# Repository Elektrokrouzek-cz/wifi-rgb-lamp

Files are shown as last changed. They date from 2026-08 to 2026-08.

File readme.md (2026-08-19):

# Wifi RGB LED Lamp
This is the construction of Wifi controlled RGB LED lamp. It is based on ESP32-C3 super mini 
module and WS2812B LED strip and WLED project.

PCB is 2-layer and was designed using KiCad 10. Fabrication output for JLCPCB is in 
gerber folder.

**Happy soldering!**

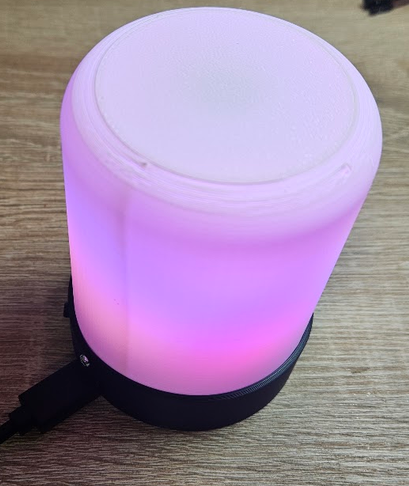
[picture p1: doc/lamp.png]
Lamp


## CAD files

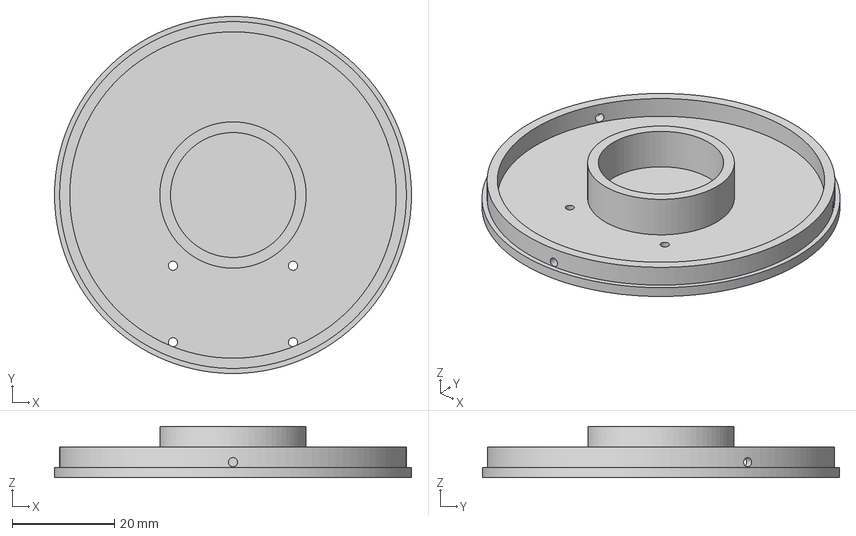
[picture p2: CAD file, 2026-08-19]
3d/lamp_middle.3mf
70.0 x 70.0 x 10.0 mm

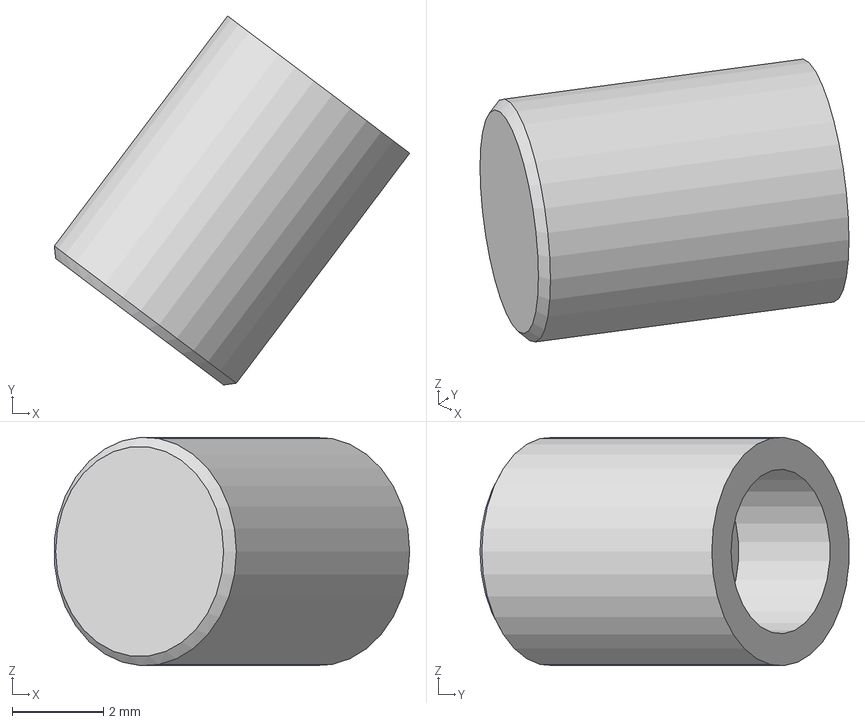
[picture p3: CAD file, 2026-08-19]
3d/lamp_button.3mf
7.77 x 8.07 x 4.99 mm

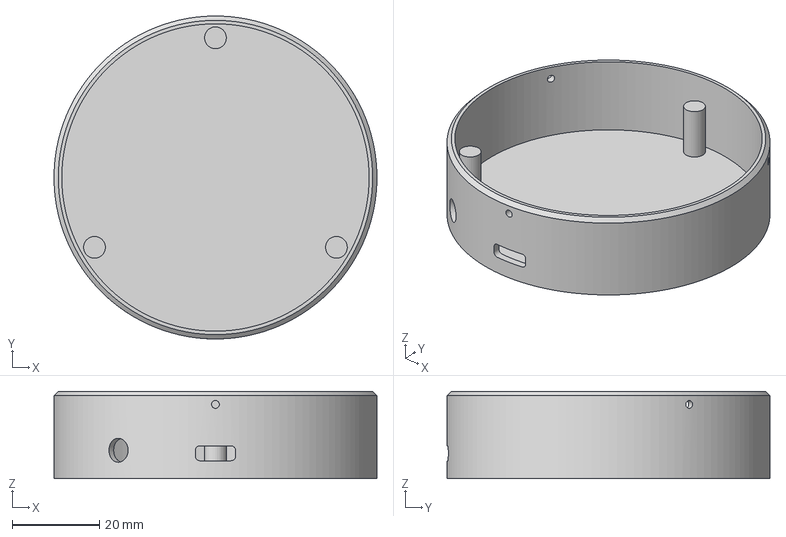
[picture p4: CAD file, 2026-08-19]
3d/lamp_bottom.3mf
74.0 x 74.0 x 20.0 mm

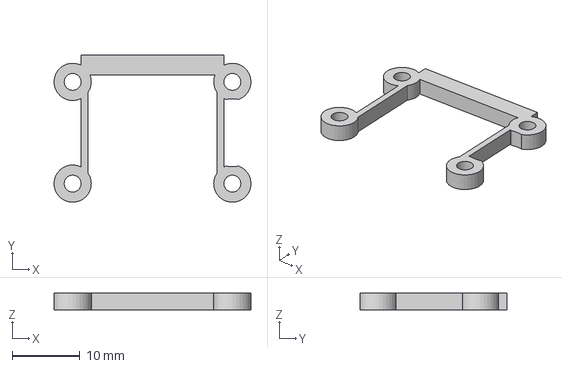
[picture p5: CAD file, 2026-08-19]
3d/lamp_pcb_spacer.3mf
29.1 x 21.7 x 2.50 mm

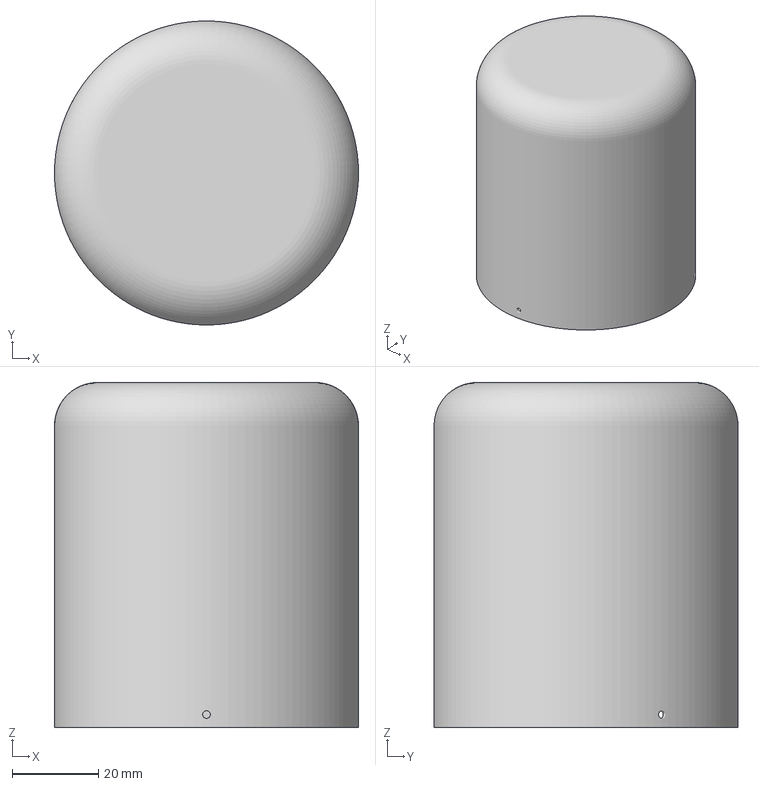
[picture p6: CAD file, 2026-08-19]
3d/lamp_cover.3mf
70.5 x 70.5 x 80.0 mm

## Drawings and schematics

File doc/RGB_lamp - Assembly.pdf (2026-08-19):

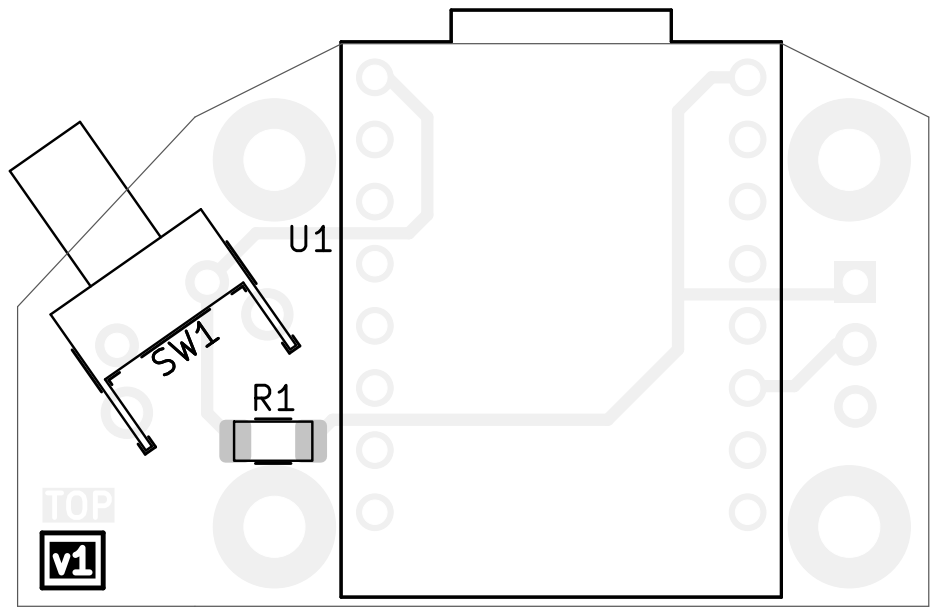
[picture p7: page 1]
D Date:; Size: A4; Rev:

Board2Pdf: Black And White TOP - Page 1/2

Sheet: Black And White TOP
File: rgb_lamp.kicad_pcb
Title:
KiCad E.D.A. 10.0.3

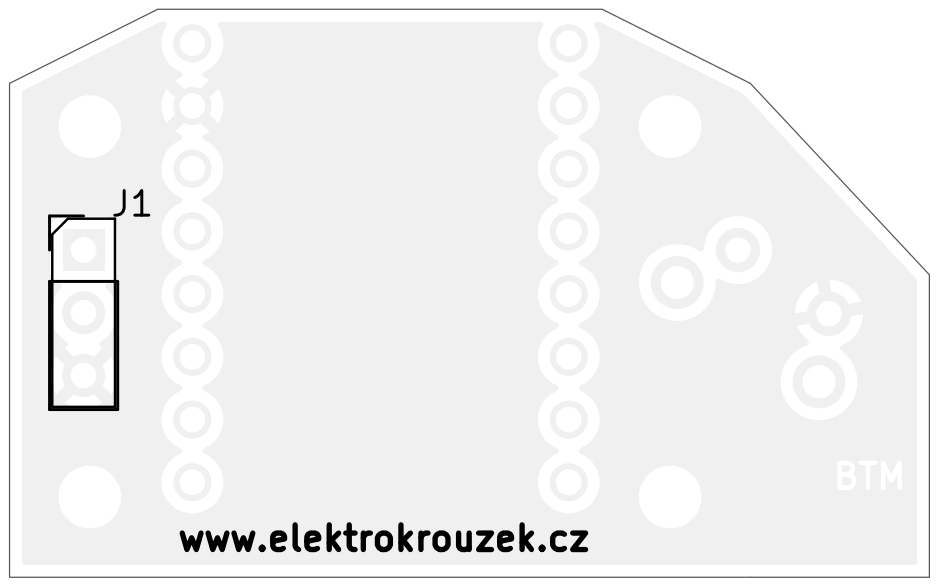
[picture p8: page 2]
D Date:; Size: A4; Rev:

www.elektrokrouzek.cz

Board2Pdf: Black And White BOT - Page 2/2

Sheet: Black And White BOT
File: rgb_lamp.kicad_pcb
Title:
KiCad E.D.A. 10.0.3

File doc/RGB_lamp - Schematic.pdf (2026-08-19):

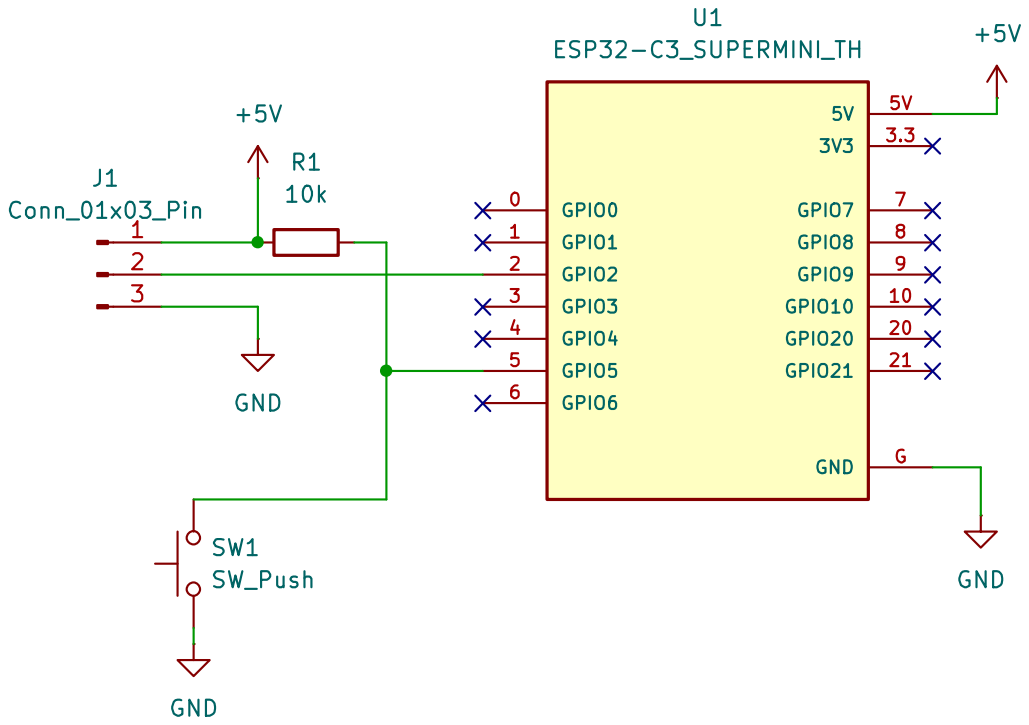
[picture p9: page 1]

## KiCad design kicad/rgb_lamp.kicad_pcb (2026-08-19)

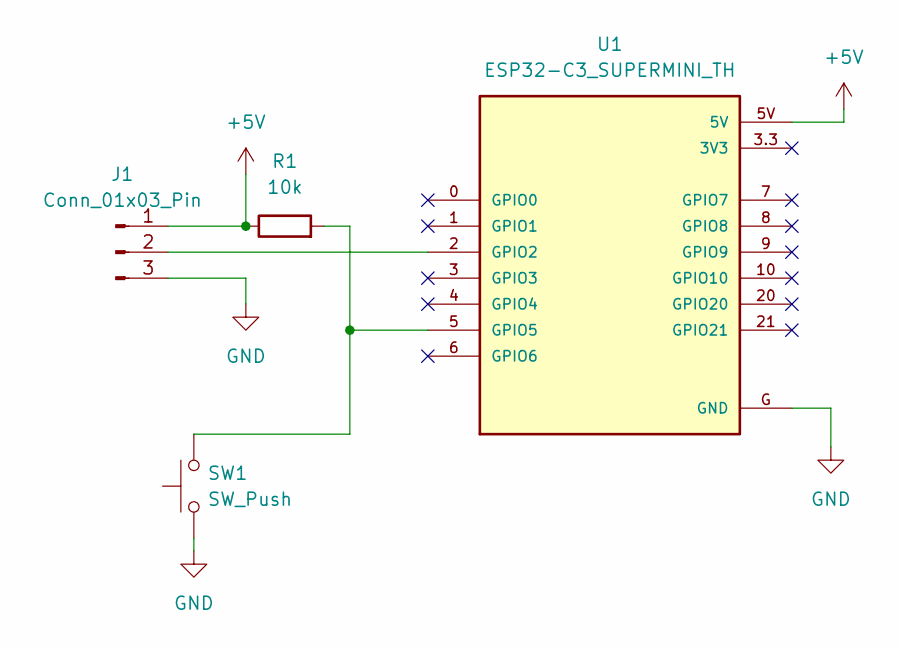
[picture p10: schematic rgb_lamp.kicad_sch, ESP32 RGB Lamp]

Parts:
J1: Conn_01x03_Pin; PinHeader_1x03_P2.54mm_Vertical
R1: 10k; R_1206_3216Metric_Pad1.30x1.75mm_HandSolder
SW1: SW_Push; SW_Tactile_SPST_Angled_PTS645Vx83-2LFS
U1: ESP32-C3_SUPERMINI_TH; MODULE_ESP32-C3_SUPERMINI

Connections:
+5V: J1.1, R1.1, U1.5V
GND: J1.3, SW1.1, U1.G (GND)
unnamed: J1.2, U1.2 (GPIO2)
unnamed: R1.2, SW1.2, U1.5 (GPIO5)

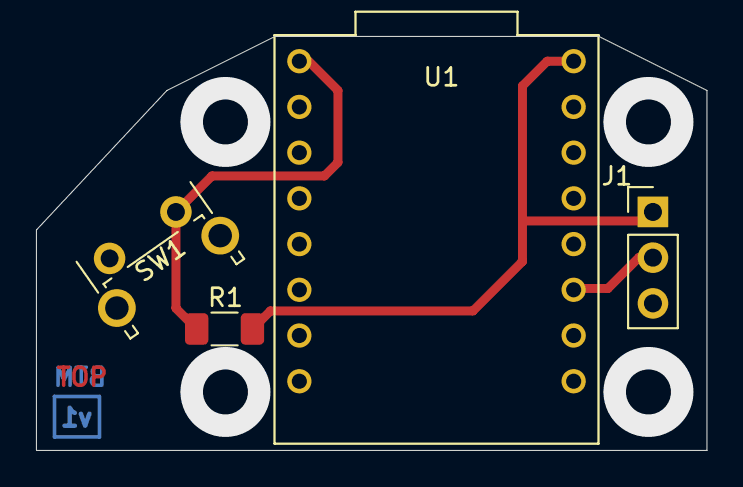
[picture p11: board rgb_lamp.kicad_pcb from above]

Board: 2 copper layers, 37.2 x 23.0 mm, 4 parts (0 on the bottom side), 4 nets.

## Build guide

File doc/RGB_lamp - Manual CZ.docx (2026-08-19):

# RGB Lampička

## Popis zapojení

Toto je velmi jednoduchá konstrukce WiFi RGB lampičky s LED páskem, která je založená na modulu ESP32-C3 super mini a projektu WLED.

## Popis sestavení

Konstrukce má součástky z jedné strany plošného spoje. Modul ESP32-C3 je do desky osazen pomocí kolíkových lišt. Jediná problematická součástka je rezistor R1 v pouzdře SMD o velikosti 1206. Vodiče k LED pásku jsou připojeny z druhé strany plošného spoje. Můžeme si opět pomoci kolíkovou lištou.

Pozor: Při zapojování LED pásku dbejte na polaritu napájení. Při přepólování by mohlo dojít k jeho zničení.

## Oživení

Nejprve je nutné naflashovat do modulu firmware WLED. Nejjednodušší způsob je pomocí webového rozhraní na adrese https://install.wled.me/. Použijte prohlížeč Chrome, který dobře funguje se sériovým rozhraním.

Postup:

1. Připojte modul pomocí USB kabelu k PC
2. Na modulu držte tlačítko BOOT a krátce stiskněte tlačítko RESET (BOOT je nutné držet během mačkání RESET)
3. Pusťte tlačítko BOOT
4. Na webu nechte výchozí nastavení a klikněte na Install

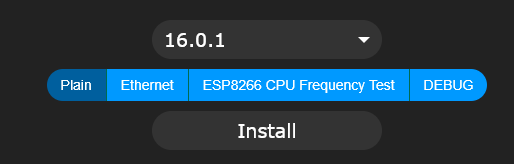
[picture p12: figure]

5. Vyberte sériový port modulu a klikněte na tlačítko Připojení
6. Vyberte Install WLED

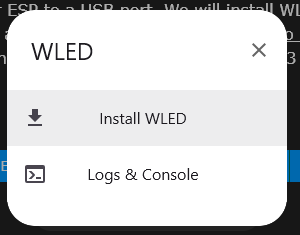
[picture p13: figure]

7. Zaškrtněte Erase device a poté klikněte na next. Potvrďte instalaci kliknutím na Install.

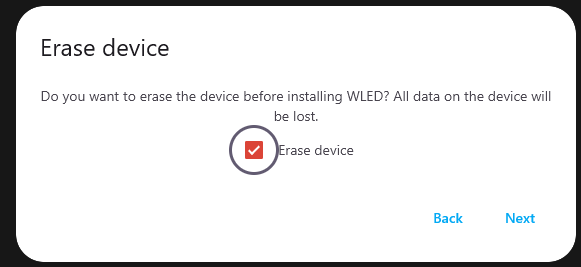
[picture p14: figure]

8. Instalace typicky zabere pouze pár sekund

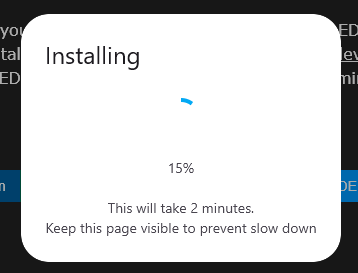
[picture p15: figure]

9. Odpojte a znovu připojte modul k USB
10. Nyní je nutné nastavit připojení modulu k vaší WiFi síti. Modul je nyní v režimu přístupového bodu a je nutné se k němu připojit. Na počítači nebo telefonu vyhledejte síť WLED-AP a připojte se k ní.

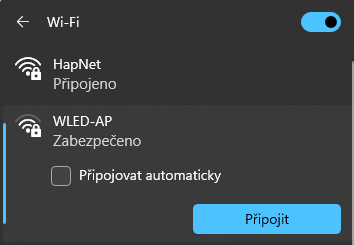
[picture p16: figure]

11. Měla by se automaticky otevřít úvodní stránka s nastavením. Klikněte na WIFI SETTINGS

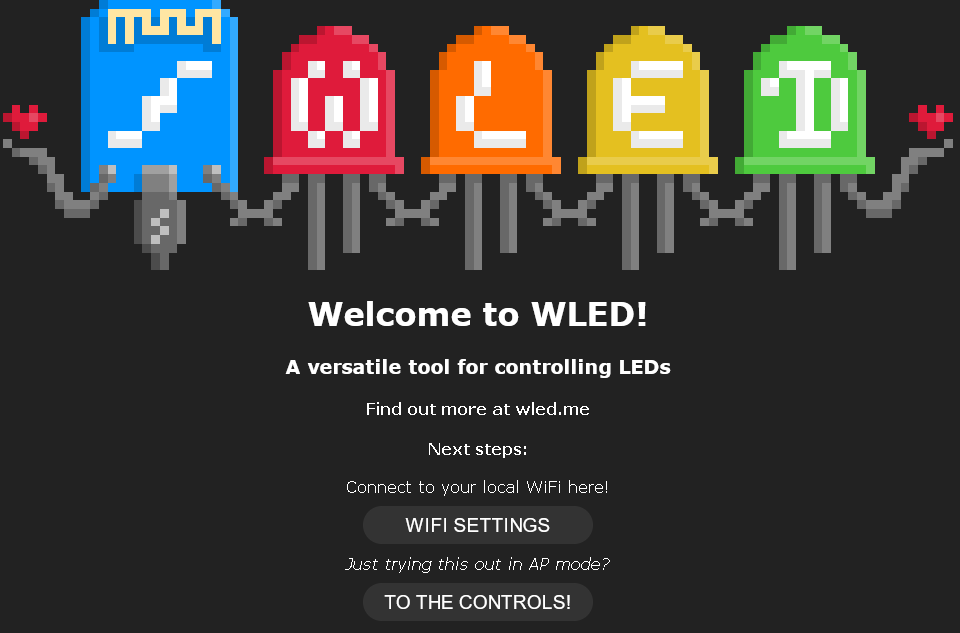
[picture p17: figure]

12. Vložte název vaší místní WiFi sítě a heslo. Následně klikněte na Save & Connect

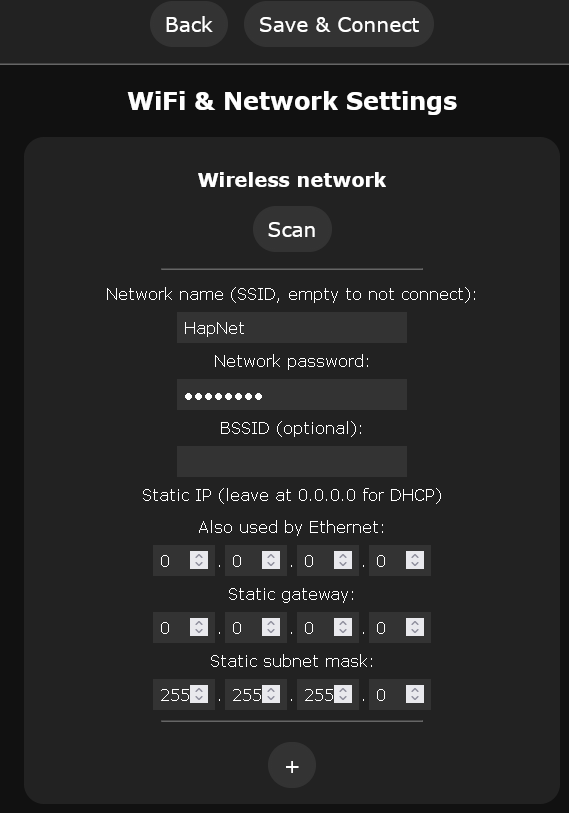
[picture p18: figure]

13. Nyní se modul restartuje a měl by se připojit k lokální síti.
14. Nainstalujte na vašem mobilním telefonu aplikaci WLED z Google Play

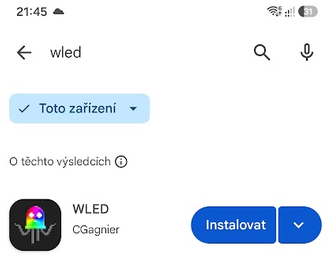
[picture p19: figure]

15. Po otevření aplikace my měl být vidět váš modul. Nyní je vše hotovo – můžete si nastavit svit vaší lampičky

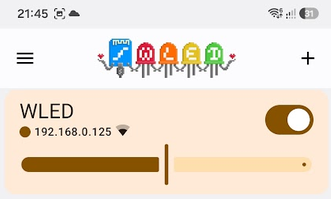
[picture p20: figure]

16. Konstrukce je zapojená tak, aby fungovalo výchozí nastavení – LED diody by měly svítit. Tlačítko je připojeno na GPIO5 a je nutné jej nastavit v záložce Config

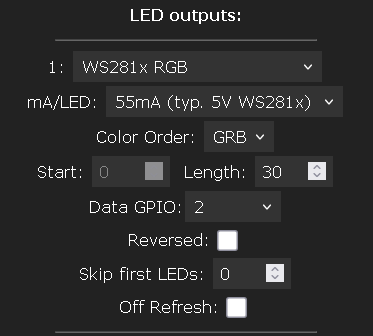
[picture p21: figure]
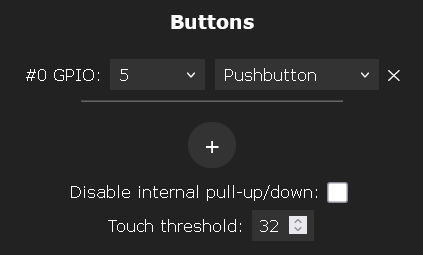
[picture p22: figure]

## Seznam součástek

Označení | Hodnota | Počet
R1 | 10k, 1206 | 1
U1 | ESP32-C3 super mini | 1
SW1 | Tlačítko 6x6mm, 90° | 1
J1 | Připojení vodičů k LED pásku
| Kolíková lišta pro U1, 2.54mm, 8 pin | 2
| RGB LED pásek WS2812B, 50cm, 60 LED/m | 50cm
| Samořezné šroubky 2.2x6.5mm (Bossard 1376012) | 7

## 3D tisk

Pro tisk krytu lampičky byl využit běžný bílý PLA filament. Rozptyluje světlo lépe než filament transparentní. Pro ostatní díly zvolte filament dle libosti.

## Mechanická konstrukce

Nejprve nalepíme LED pásek do šroubovice na vnitřní trubku. Začneme od horního okraje. Pokud by se pásek odlepoval, přilepíme jej pomocí vteřinového lepidla.

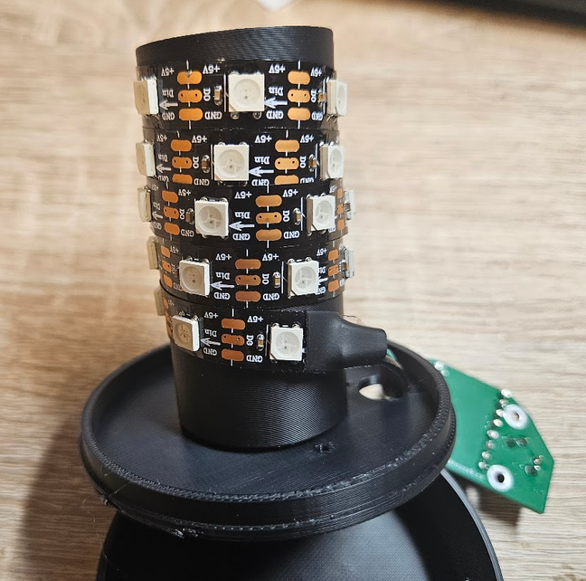
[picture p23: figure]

Následně provlékneme vodiče od LED pásku skrz střední díl a připájíme je do desky plošných spojů. Trubku s LED páskem můžeme přilepit vteřinovým lepidlem.

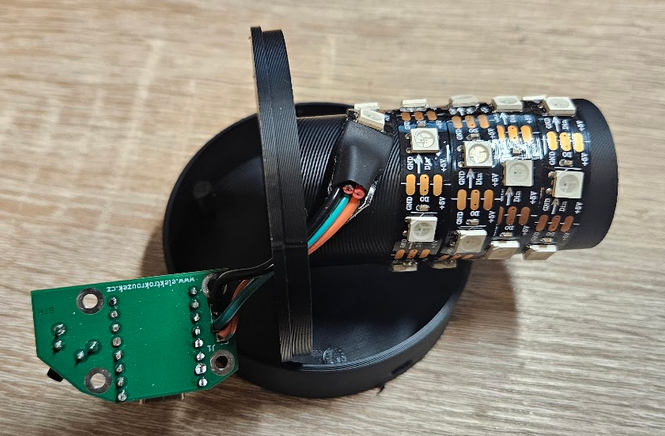
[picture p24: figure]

Plošný spoj přišroubujeme do středního dílu přes vymezovací díl.

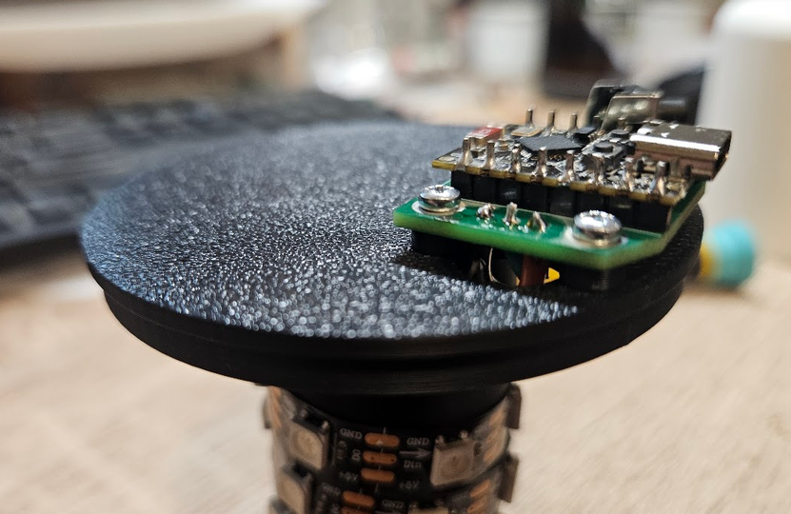
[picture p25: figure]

Na tlačítko přilepíme hmatník

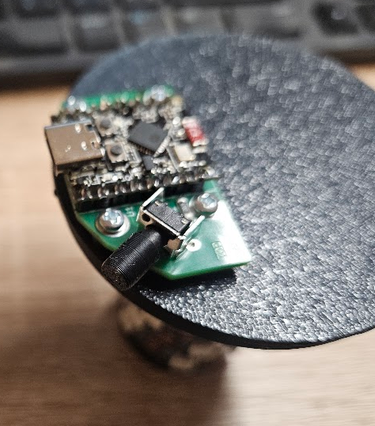
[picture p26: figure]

A celou konstrukci vložíme do spodního dílu

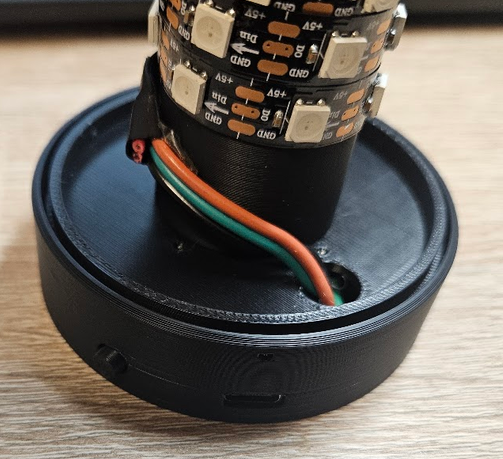
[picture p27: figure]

Vložíme horní kryt a zajistíme pomocí 3 šroubků

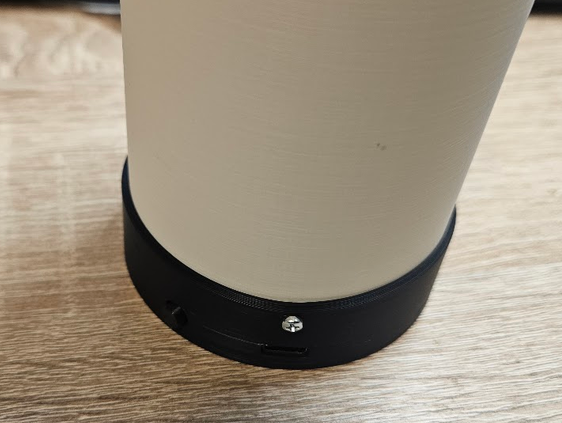
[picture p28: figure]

## Osazovací výkresy

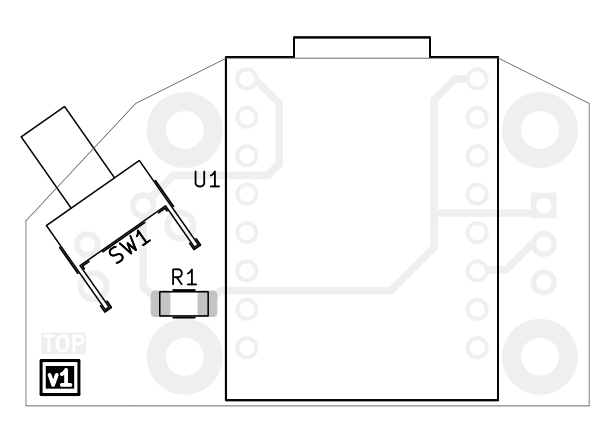
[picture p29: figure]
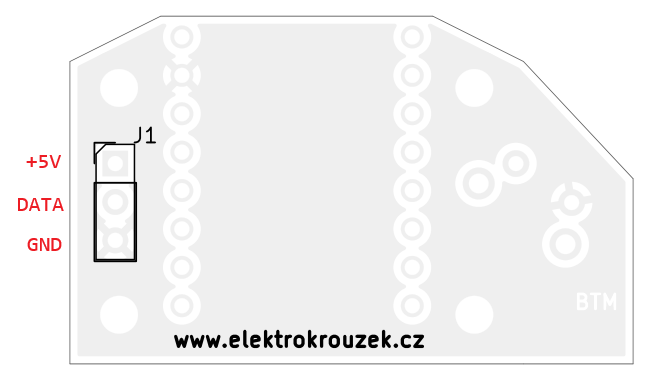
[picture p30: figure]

## Schéma zapojení

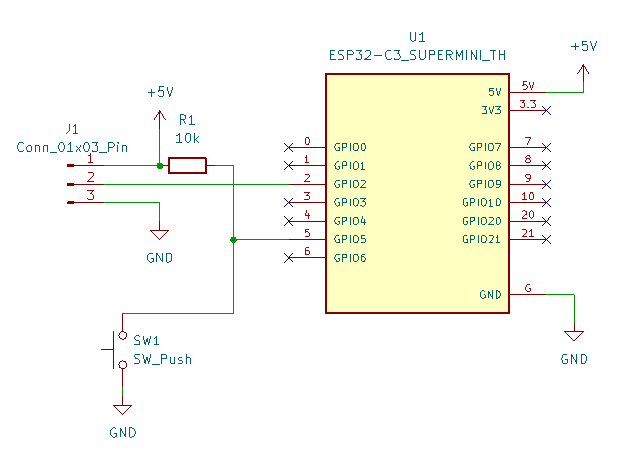
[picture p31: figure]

www.elektrokrouzek.cz

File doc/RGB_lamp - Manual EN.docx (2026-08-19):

# RGB Lamp

## Schematic description

This is a very simple design for a WiFi RGB lamp using an LED strip, based on the ESP32-C3 Super Mini module and the WLED project.

## Construction

The assembly features components mounted on one side of the PCB. The ESP32-C3 module is attached to the board using pin headers. The only challenging component is resistor R1, which comes in a 1206 SMD package. The wires for the LED strip are connected to the opposite side of the PCB; a pin header can be used here as well to facilitate the connection.

Caution: Observe the correct power supply polarity when connecting the LED strip. Reversing the polarity could destroy it.

## How to get it into service

First, you need to flash the WLED firmware onto the module. The easiest way is to use the web interface at https://install.wled.me/. Use the Chrome browser, as it works well with the serial interface.

Procedure:

1. Connect the module to your PC using a USB cable.
2. Hold down the BOOT button on the module and briefly press the RESET button (you must keep holding BOOT while pressing RESET)
3. Release the BOOT button.
4. Leave the default settings on the webpage and click Install.


5. Select the module's serial port and click the Connect button
6. Select Install WLED


7. Check Erase device and then click next. Confirm the installation by clicking Install.


8. Installation typically takes only a few seconds


9. Disconnect and connect the module to USB
10. Now you need to configure the module's connection to your Wi-Fi network. The module is currently in access point mode, and you need to connect to it. Search for the "WLED-AP" network on your computer or phone and connect to it.


11. The initial settings page should open automatically. Click on WIFI SETTINGS.


12. Enter the name of your local Wi-Fi network and the password. Then click Save & Connect.


13. The module will now restart and should connect to the local network.
14. Install the WLED app on your mobile phone from Google Play.


15. After opening the app, your module should be visible. Everything is now set up—you can adjust the brightness of your lamp.


16. The circuit is wired to work with the default settings – the LEDs should light up. The button is connected to GPIO5 and must be configured in the Config tab.


## Bill of materials

Annotation | Value | Qty
R1 | 10k, 1206 | 1
U1 | ESP32-C3 super mini | 1
SW1 | Button 6x6mm, 90° | 1
J1 | Connection to the LED strip
| Pin header for U1, 2.54mm, 8 pin | 2
| RGB LED strip WS2812B, 50cm, 60 LED/m | 50cm
| Screw 2.2x6.5mm (Bossard 1376012) | 7

## 3D print

Standard white PLA filament was used to print the lamp shade. It diffuses light better than transparent filament. For the other parts, choose the filament of your choice.

## Mechanical construction

First, adhere the LED strip to the inner tube in a helical pattern, starting from the top edge. If the strip starts to peel off, secure it with super glue.


Next, thread the LED strip wires through the center piece and solder them to the printed circuit board. The tube containing the LED strip can be secured with super glue.


Screw the printed circuit board onto the middle section using the spacer.


We glue the tactile cap onto the button.


And we insert the entire assembly into the bottom part.


Insert the top cover and secure it with 3 screws.


## PCB assembly


## Schematic


www.elektrokrouzek.cz
